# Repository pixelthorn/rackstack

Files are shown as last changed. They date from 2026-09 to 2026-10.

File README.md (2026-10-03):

# rackstack

display

This repo is reorganized version of the [original repo](https://github.com/jazwa/rackstack) with some added rack mounts for personal use. 

### A modular 3d-printable mini rack system
- ***Mount Anything:*** Perfect for organizing SBCs, mini PCs, small switches, power hubs, etc.
- ***Fully customizable:*** Fully written in OpenSCAD. Everything, from the dimensions of the rack, to the roundness of the corners, can be modified with a simple code change.
- ***Printable from home:*** Designed to be printed with conventional FDM printers. Requires minimal supports when printing, and final assembly needs only a few easy-to-source parts. 
- ***No cage nuts:*** Sliding hex nut design for the front rails allows one to easily mount items, without dealing with cage nuts.
- ***Stackable:*** Individual racks can be easily stacked and fastened together. Mix and match different color and design combinations!

## Assembly

Pre-generated STLs for roughly 200mm^3 (mini), 180mm^3 (micro), and 100mm^3 (nano) rack frames can be found in the [stl](stl) dir.
These STLs are generated from the files in [rack/print](rack/print) - further information about printing these parts 
(supports, orientation) can be found in these files.

### Assembly Instructions
Please see [the assembly guide](./assembly-guide).

### BOM - Required Tools:
- 3d FDM Printer - build size requirements depend on configured rack profile
- M3 Allen Key (for constructing the rack)
- M4 Allen Key (for mounting rack-mount items)

### BOM - Single Rack:

| Item | Name | Quantity | Comment |
|---|---|---|---|
|  | M3x12 FHCS | 12 | Extras are useful and inexpensive. If you plan on eventually stacking multiple racks together, don't hesitate to get a lot more. |
|  | M3x16 FHCS | 16 | ☝️ |
|  | M3 hex nut | 28 | ☝️ |
|  | 3x10 steel dowel pin | 4 | 3mm diameter, 10mm height |
|  | 6x2 neodymium disc magnet | 8 | 6mm diameter, 2mm height |
|  | super glue | \>= 2ml  | Used to glue magnets to plastic |

### Printing - Single Rack:
| Part | Quantity |
|---|---|
| [Left Y-Bar](./rack/print/yBarLeft_P.scad) | 2 |
| [Right Y-Bar](./rack/print/yBarRight_P.scad) | 2 |
| [X-Bar](./rack/print/xBar_P.scad) | 4 |
| [Main Rail](./rack/print/mainRail_P.scad) | 4 |
| [Left Side Wall](./rack/print/sideWallLeft_P.scad) | 1 |
| [Right Side Wall](./rack/print/sideWallRight_P.scad) | 1 |
| [XY-Plate](./rack/print/xyPlate_P.scad) | 2 |
| [Feet](./rack/print/rackFeet_P.scad) (optional) | 2 |

#### Notes: 
- ⚠️ Before printing the actual parts. It's recommended to print this evaluation part: [eval_P.scad](./rack/print/eval_P.scad) to test tolerances. 
  If you find the fits too tight/loose, you can adjust them [here](./config/print.scad). Please make sure also adjust the layer height in that file, too.
- Omitted actual plastic for printing. Any conventional 3d printing plastic should do (PLA, PETG, ABS),
but beware of PLA's thermal limits. Higher infill is recommended for all parts.
- For joining two racks, you will need to print 4 [rackJoiners](./rack/print/rackJoiner_P.scad), as well as 8 M3 hex nuts, and 8 M3x12 FHCS.
- Main front rails use M4 hex nuts and screws.
- Side rails are mounted using M3 hex nuts and screws.

## Configuring + Generating STLs
A python script:  [rbuild.py](./rbuild.py) is provided to generate different project stls. **Before running the script**, please 
configure the path to the OpenSCAD binary in [rbuild.py](./rbuild.py).

Requirements:
  - `openscad` CLI binary
  - `python3`

### Examples:
Generate all project files for the `micro` profile:

`python3 rbuild.py -b all -c micro`

This will build all the parts defined in [rack/print](./rack/print), and put the STLs in [stl/micro](./stl/micro). 
You can also provide a `-dz {n}` parameter to adjust the height of the generated rack. Configuring other rack
variables can be done in [config/rackframe.scad](./config/rackFrame.scad).

For generating a specific part, and putting it into a new `stl/custom` target directory: 

`python3 rbuild.py -b yBar -c micro -t custom`

`rbuild.py` also support an optional `--nightly` flag, which will run a nightly build of OpenSCAD. Please make sure the
path to the nightly build is also configured in [rbuild.py](./rbuild.py).

### ⚠️ Important:
Before committing to a full print, please try printing an evaluation print: [eval_P.scad](./rack/print/eval_P.scad) to test tolerances.
It is very likely you will need to edit the default tolerances in [print.scad](./config/print.scad) for a nice fit.
Confirm that your screw and nut sizes in [screws.scad](helper/screws.scad) and adjust if needed. Nuts, especially, may vary slightly.

## Trays, Boxes, etc

Some parametric rack mount systems can be found in [rack-mount](./rack-mount). The following rack-mount systems 
are currently supported:
- [Enclosed Box](./rack-mount/boxes/enclosed-box): For mounting box-shaped objects, without the need for any mounting holes on the box.
- [Tray](./rack-mount/trays/tray): Simple tray mounted using only the front rails. Can be configured to have screw mounts at the bottom of the tray.
- [Patch Panel](./rack-mount/panels/patch-panel): Linear patch panel array. Number of keystone slots can be configured.
- [Angle Brackets](./rack-mount/angle-bracket): Simple Angle Bracket mounting system. Derived from the Enclosed Box system.

Additional user generated mounts can be found under [rack-mount](./rack-mount) as well. 

### Generating STLs for Rack Mount parts

Make sure that the correct profileName is set in [rackframe.scad](./config/rackFrame.scad)! 
Use OpenSCAD or another CAD program to open entry.scad (or other main scad file) in the subfolder and render it then export as STL.

## Designing rack-mount items

Some useful variables for designing your own rack-mount items can be found in [rack-mount/dimensionHelper.scad](./rack-mount/dimensionHelper.scad).

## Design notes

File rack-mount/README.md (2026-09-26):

# Rack Mount Catalog

A hodgepodge of various pre-configured rack mount parts. 

Command to rebuild the preview images:
`find . -name "*.scad" -exec ./build_catalog_preview.sh {} \;`

Rebuild a single image:
`./build_catalog_preview.sh <path/to/filename.scad`

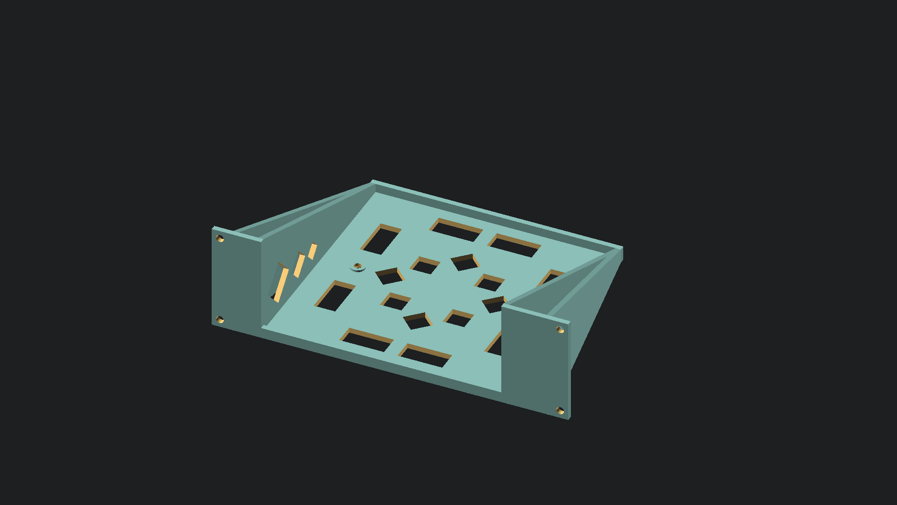
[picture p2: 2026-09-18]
rack-mount/trays/Minisforum_NAB9_tray/Minisforum_NAB9-tray_mod.png

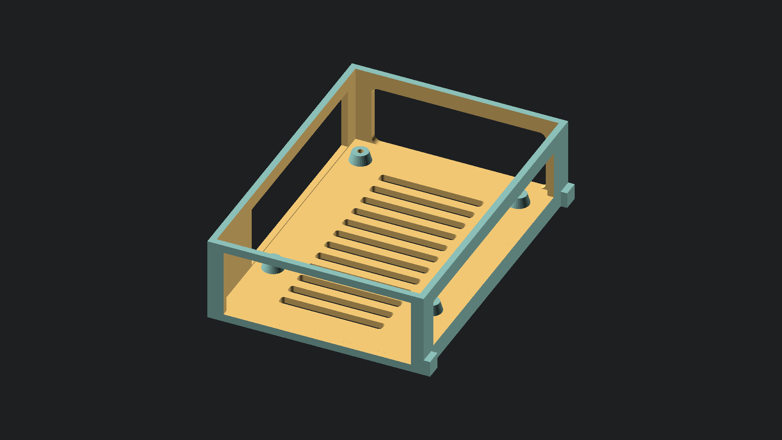
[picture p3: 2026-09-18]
rack-mount/boxes/rpi-sbc-simple-box/case.png

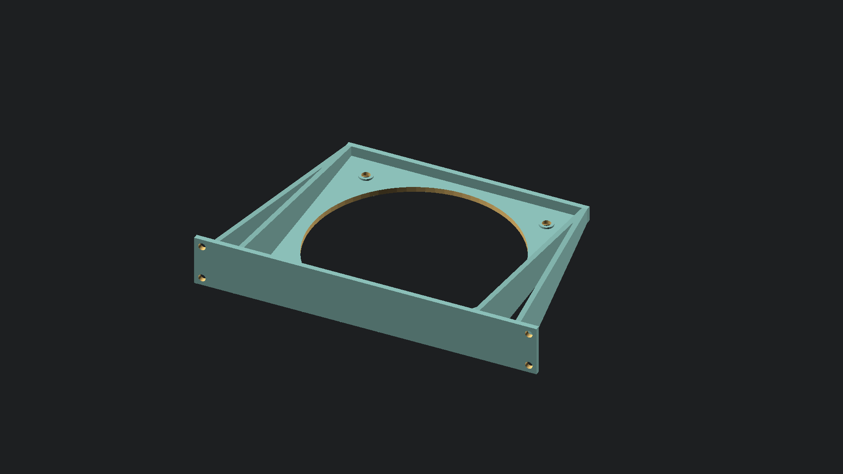
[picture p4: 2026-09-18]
rack-mount/trays/120mm_fan_tray/120mm-fan-tray_mod.png

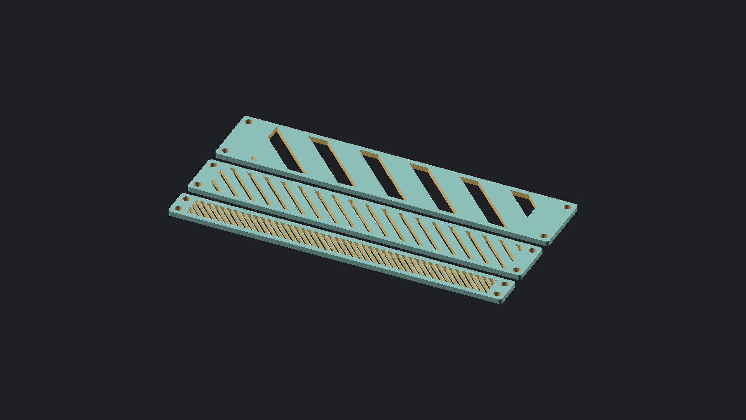
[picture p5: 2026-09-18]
rack-mount/plates/ventilated-plate/ventilated_plate.png

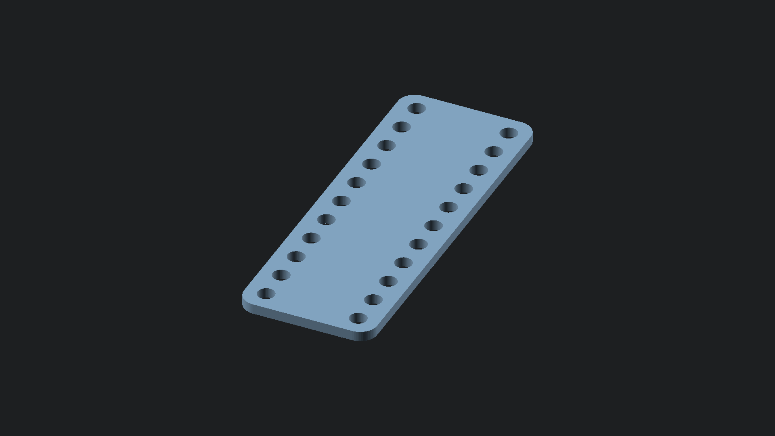
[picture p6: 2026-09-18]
rack-mount/plates/screw-plate/screwplate.png

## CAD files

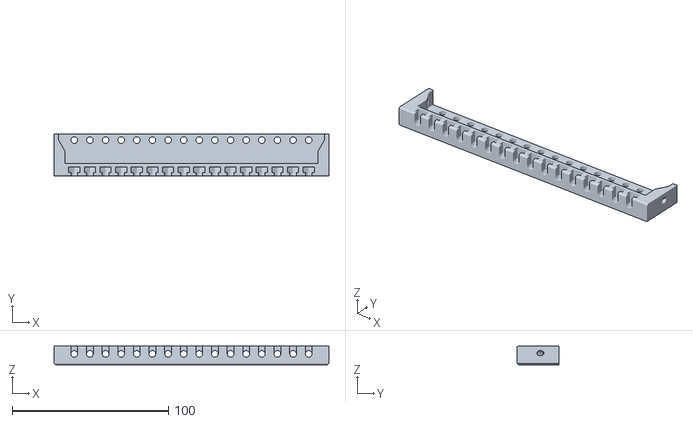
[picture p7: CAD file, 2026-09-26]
stl/mini/rack/mainRail_P.stl
176.0 x 27.0 x 12.0

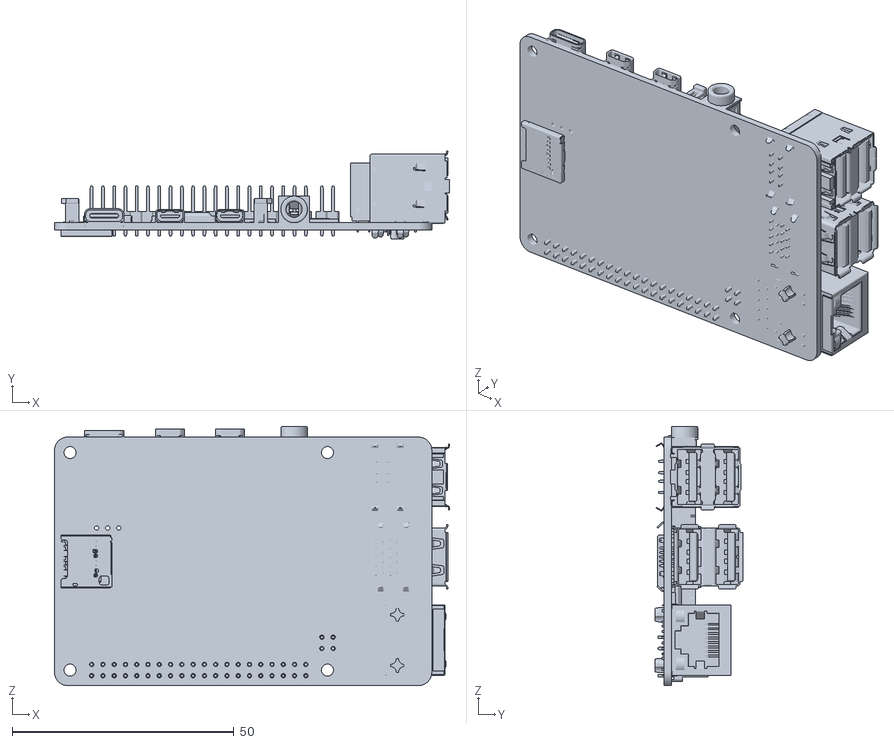
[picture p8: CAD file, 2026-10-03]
rack-mount/trays/raspberry_pi_4b_tray/Raspberry Pi 4 Model B.stl
89.0 x 19.9 x 58.4

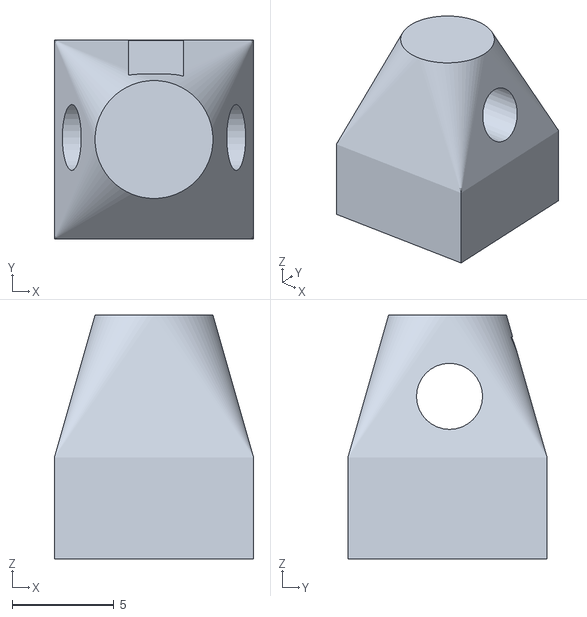
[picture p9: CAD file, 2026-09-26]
stl/mini/rack/stackConnectorBottom_P.stl
9.80 x 9.80 x 12.0

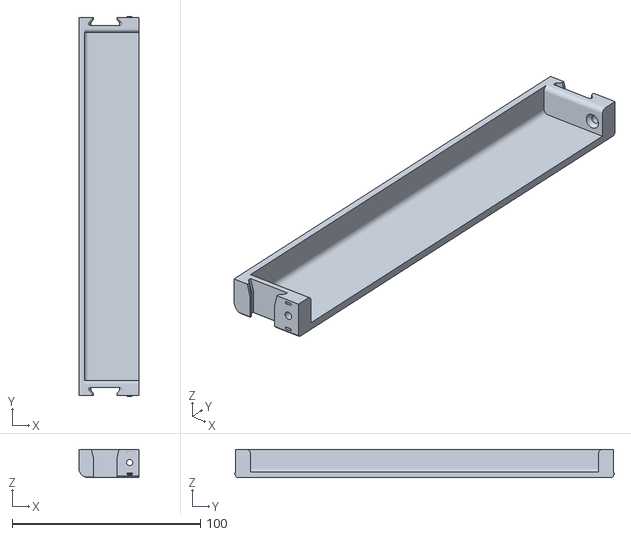
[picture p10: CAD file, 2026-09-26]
stl/mini/rack/xBar_P.stl
32.0 x 201.8 x 15.0

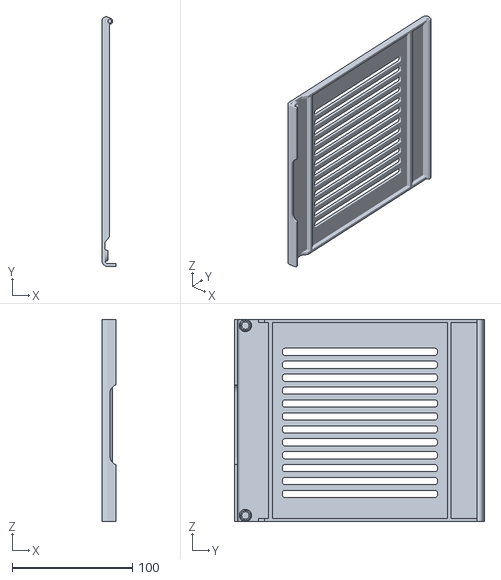
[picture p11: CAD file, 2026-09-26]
stl/mini/rack/sideWallLeft_P.stl
11.8 x 208.3 x 168.4

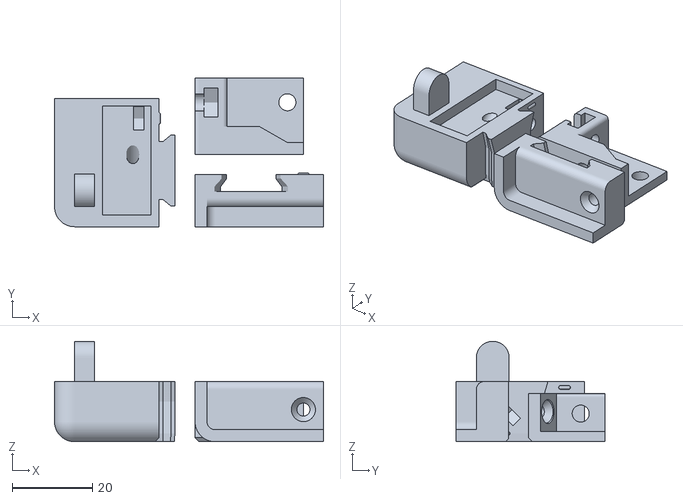
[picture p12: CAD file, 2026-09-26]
stl/mini/rack/eval_P.stl
67.0 x 37.0 x 25.0

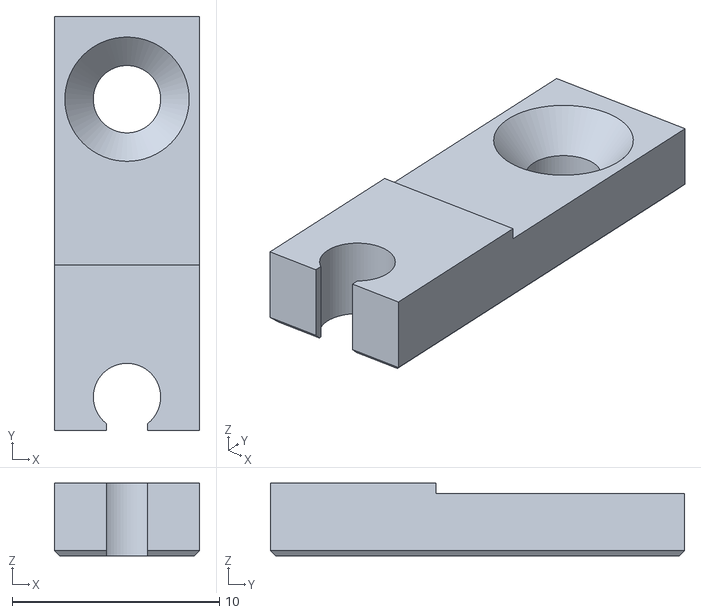
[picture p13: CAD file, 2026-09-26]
stl/mini/rack/hingeModule.stl
7.00 x 20.0 x 3.50

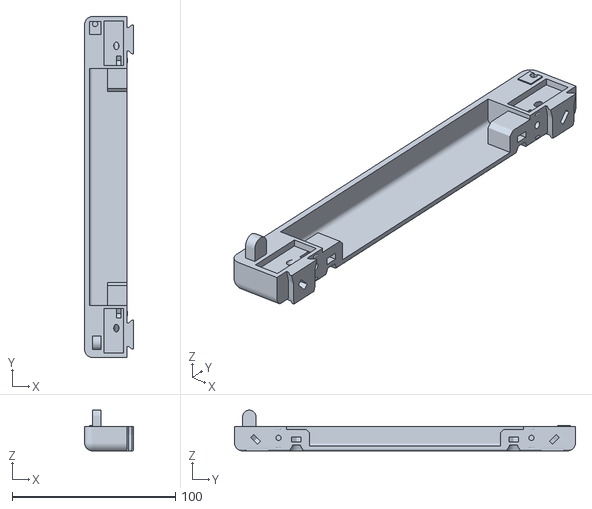
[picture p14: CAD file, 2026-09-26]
stl/mini/rack/yBarLeft_P.stl
30.0 x 209.0 x 25.0

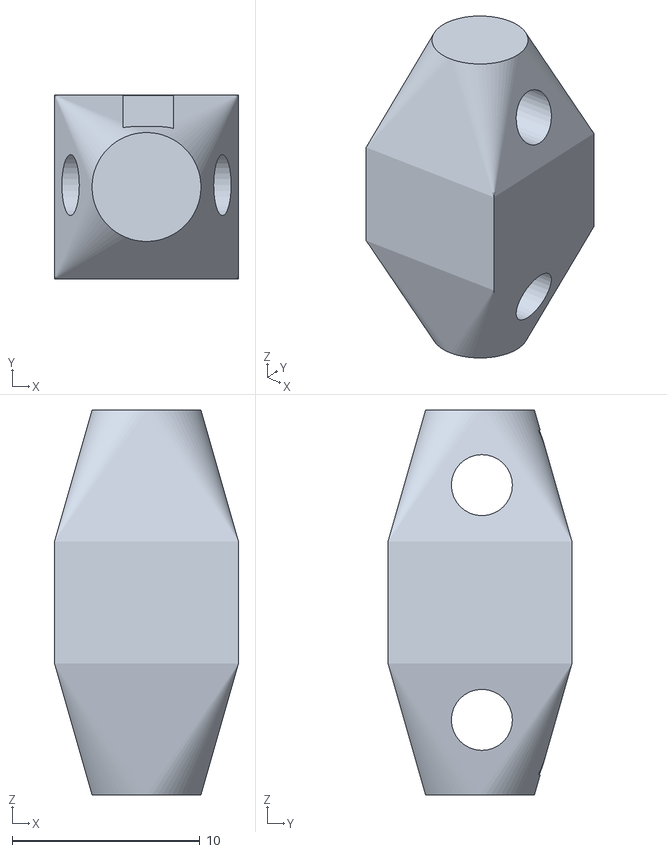
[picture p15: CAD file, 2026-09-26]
stl/mini/rack/rackJoiner_P.stl
9.80 x 9.80 x 20.5

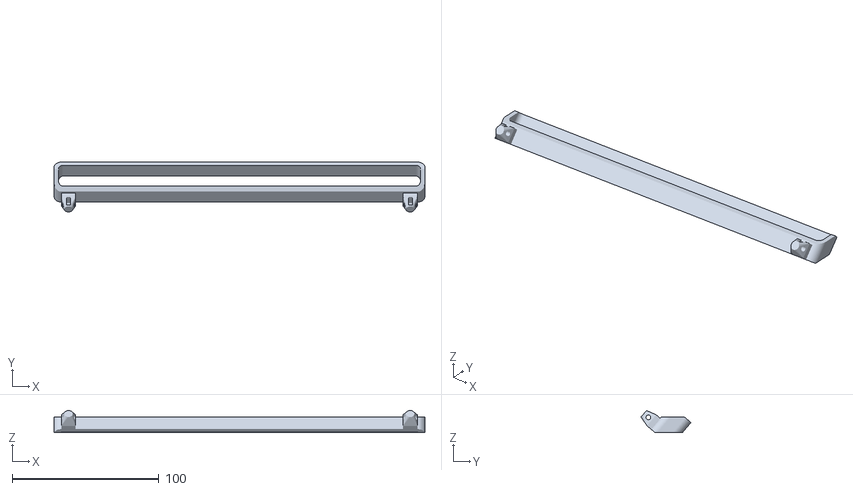
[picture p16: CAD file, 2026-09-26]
stl/mini/rack/rackFeet_P.stl
253.0 x 34.0 x 15.0

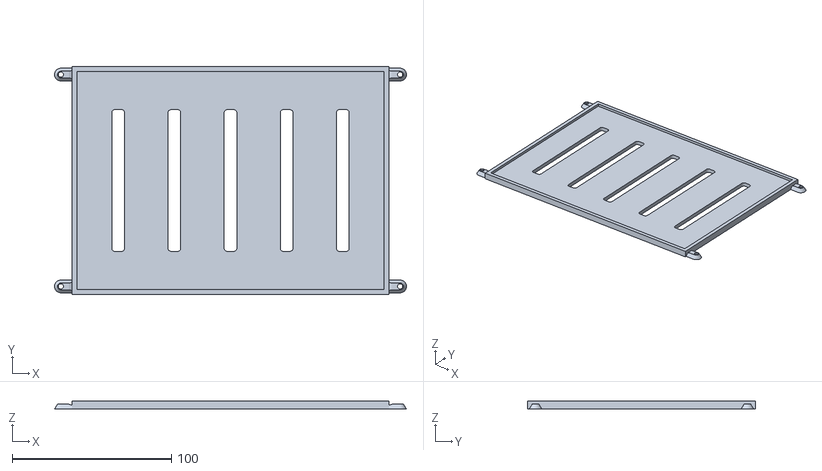
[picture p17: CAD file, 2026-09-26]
stl/mini/rack/xyPlate_P.stl
221.0 x 143.0 x 5.00

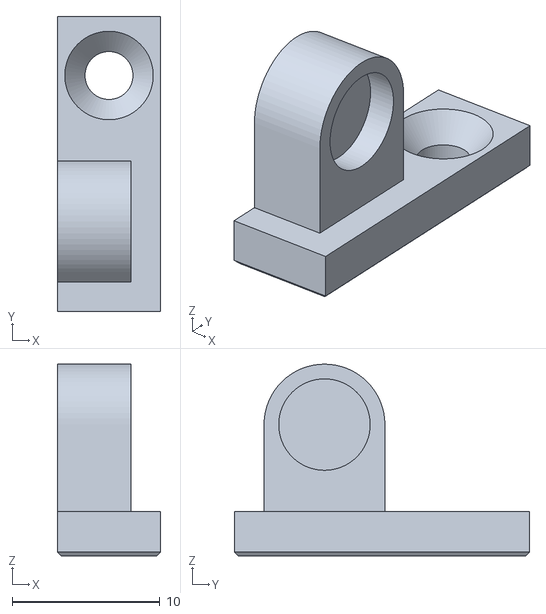
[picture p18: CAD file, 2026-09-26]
stl/mini/rack/magnetModuleRight_P.stl
7.00 x 20.0 x 13.0

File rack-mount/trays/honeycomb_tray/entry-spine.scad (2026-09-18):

use <./tray-honeycomb-spine.scad>

/*
  Parametric rack-mount tray:
  Dimensions can be adjusted using the variables below. You can also add mounting holes to fasten things that have
  screw holes at the bottom.

  !!! Please also make sure that the correct rack frame preset is set in rackFrame.scad !!!
*/

module traySystem (

trayU = 2,

baseWidth = 195,
baseDepth = 185,

baseThickness = 3,
frontThickness = 3,
sideThickness = 3,

backLipHeight = 2,
frontLipHeight = 2,

sideSupport = false,
trayLeftPadding = 10,

mountPointType = "m3",
mountPointElevation = 1,

mountPoints = [],

// Honeycomb
hex_side = 4.0,
cell_wall = 1.5,
rim_width = 3.0

) {

  bottomScrewTray (
    u = trayU,
    trayWidth = baseWidth,
    trayDepth = baseDepth,
    trayThickness = baseThickness,
    frontLipHeight = frontLipHeight,
    backLipHeight = backLipHeight,
    mountPoints = mountPoints,
    frontThickness = frontThickness,
    sideThickness = sideThickness,
    mountPointElevation = mountPointElevation,
    mountPointType = mountPointType,
    sideSupport = sideSupport,
    trayLeftPadding = trayLeftPadding,
    hex_side = hex_side,
    cell_wall = cell_wall,
    rim_width = rim_width
  );
}

traySystem();

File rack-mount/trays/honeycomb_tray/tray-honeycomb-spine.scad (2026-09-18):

include <../../common.scad>
use <../../rackEars.scad>

// --- honeycomb helpers, lifted from catalog/honeycomb-tray/entry.scad ---
module __hex2d(side) {
    polygon(points=[ for (i=[0:5]) [ side*cos(60*i), side*sin(60*i) ] ]);
}

module __honeycomb_plate(width, depth, plate_h, side, wall, rim, spine_x=-1, spine_w=0) {
    difference() {
        cube([width, depth, plate_h], center=false);
        x_step = 1.5 * side;
        y_step = sqrt(3) * side;
        w = width - 2*rim;
        d = depth - 2*rim;
        translate([rim, rim, 0])
        union() {
            for (ix = [0 : ceil(w / x_step) + 1]) {
                x = side + ix * x_step;
                y_off = (ix % 2) * (y_step/2);
                for (iy = [0 : ceil(d / y_step) + 1]) {
                    y = y_off + iy * y_step;
                    // skip any hex whose center falls inside the spine band
                    inSpine = (spine_w > 0) && (abs((x+rim) - spine_x) < spine_w/2 + side);
                    if (x >= 0 && x <= w && y >= 0 && y <= d && !inSpine) {
                        translate([x, y, 0])
                            linear_extrude(height=plate_h + 0.05)
                                __hex2d(max(0.01, side - wall));
                    }
                }
            }
        }
    }
}

module bottomScrewTray(u, trayWidth, trayDepth, trayThickness, mountPoints, mountPointElevation, mountPointType, frontThickness, sideThickness, frontLipHeight, backLipHeight, trayLeftPadding, sideSupport=true,
  hex_side=6, cell_wall=1.5, rim_width=3) {   // <-- new honeycomb params

  lipThickness = sideThickness;
  screwDx = rackMountScrewWidth;
  screwDz = uDiff * u;
  plateLength = screwDx + 2*rackMountScrewXDist;
  plateHeight = screwDz + 2*rackMountScrewZDist;
  minScrewToTraySpacing = railScrewHoleToInnerEdge;
  leftScrewDistToTray = minScrewToTraySpacing + trayLeftPadding;
  leftScrewGlobalX = -leftScrewDistToTray;
  rightScrewGlobalX = screwDx + leftScrewGlobalX;

  assert(trayWidth <= screwDx-(2*minScrewToTraySpacing + trayLeftPadding));

  difference() {
    applyMountHoles()
    translate(v = [-sideThickness, -frontThickness, -trayThickness])
    body();
  }

  module body() {

    // honeycomb base instead of a solid cube
    __honeycomb_plate(trayWidth, trayDepth, trayThickness, hex_side, cell_wall, rim_width, spine_x=trayWidth/2, spine_w=14);

    // front lip
    translate(v = [0, 0, trayThickness])
    cube(size = [trayWidth, lipThickness, frontLipHeight]);

    // back lip
    translate(v = [0, trayDepth-lipThickness, trayThickness])
    cube(size = [trayWidth, lipThickness, backLipHeight]);

    translate(v = [leftScrewGlobalX, 0, rackMountScrewZDist])
    rackEarModule(frontThickness = frontThickness, sideThickness = sideThickness, frontWidth =
        leftScrewDistToTray+rackMountScrewXDist+sideThickness, sideDepth = trayDepth-lipThickness, u = u, backPlaneHeight=trayThickness+backLipHeight, support=sideSupport);

    translate(v = [rightScrewGlobalX, 0, rackMountScrewZDist])
    mirror(v = [1, 0, 0])
    rackEarModule(frontThickness = frontThickness, sideThickness = sideThickness, frontWidth =
       rightScrewGlobalX-trayWidth+rackMountScrewXDist+sideThickness, sideDepth = trayDepth-lipThickness, u = u, backPlaneHeight=trayThickness+backLipHeight, support=sideSupport);
  }

  module applyMountHoles() {
    mountPointPosThickness = 2;
    if (len(mountPoints) > 0) {
      apply_pn() {
        for (i = [0:len(mountPoints)-1]) {
          x = mountPoints[i][0]; y = mountPoints[i][1];
          translate(v = [x, y, 0])
          cylinder(r = screwRadiusSlacked(mountPointType)+mountPointPosThickness, h = mountPointElevation);
        }
        for (i = [0:len(mountPoints)-1]) {
          x = mountPoints[i][0]; y = mountPoints[i][1];
          translate(v = [x, y, -trayThickness])
          mirror(v = [0, 0, 1])
          counterSunkHead_N(mountPointType, inf, inf);
        }
        children(0);
      }
    } else {
      children(0);
    }
  }
}

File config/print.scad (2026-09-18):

// Print settings config file

/**********************************************************************************************************************
  Slack config to standardize different usages of slack/tolerance values.

  The purpose of this config is to introduce some consistency with how slack values defined in code. E.g. Why is the
  slack value defined as 0.3 in this file, but 0.4 in another? This will also allow model-level adjustments for tighter
  fitting parts, for when it might not convenient to adjust the actual 3d printer (using a 3d printer at a makerspace,
  for example).

  Some important details:
    - The general philosophy for slack applications in this project is to subtract space from sockets, while not
      modifying the plugs.
    - Values are signed. Positive values can be interpreted as how much to remove from the socket along some dimension.
    - These values depend on print orientation and it's assumed parts are printed in their recommended orientations.
*/
xySlack = 0.25;

radiusXYSlack = xySlack/2;

zSlack = 0.0;

overhangSlack = 0.5;

supportedOverhangSlack = 0.5;

// special slack cases, change if neccessary
xBarYBarDovetailSlack = xySlack;

/**********************************************************************************************************************
  Printer/slicer config, mainly used for calculating some special overhangs.
*/
defaultLayerHeight = 0.2;

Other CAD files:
stl/mini/rack/sideWallRight_P.stl
stl/mini/rack/yBarRight_P.stl
stl/mini/rack/magnetModuleLeft_P.stl
config/rackFrame.scad
helper/screws.scad
misc/component.scad
misc/device_raspberrypi.scad
misc/misc_boards.scad
misc/misc_parts.scad
rack-mount/angle-bracket/entry.scad
rack-mount/angle-bracket/entry_customizers.scad
rack-mount/boxes/enclosed-box/animate.scad
rack-mount/boxes/enclosed-box/entry.scad
rack-mount/boxes/enclosed-box/entry_customizers.scad
rack-mount/boxes/enclosed-box/entry_plate_only.scad
rack-mount/boxes/enclosed-box/frontBoxHolder.scad
rack-mount/boxes/enclosed-box/helper.scad
rack-mount/boxes/enclosed-box/sideRail.scad
rack-mount/boxes/rpi-sbc-simple-box/case.scad
rack-mount/boxes/rpi-sbc-simple-box/frontPlate.scad
rack-mount/boxes/rpi-sbc-simple-box/top.scad
rack-mount/boxes/sfxPSU/sfxPSU.scad
rack-mount/boxes/single-bracket-box/entry.scad
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

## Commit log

2026-09-18 organized rack-mount items into subdirectories
    [10-zoll_Raspberry_pi_4-DualMount_ohne_text.3mf, 10-zoll_Raspberry_pi_4-DualMount_ohne_text.scad, 10-zoll_Raspberry_pi_4-DualMount_ohne_text.stl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]
2026-09-18 removed unneeded file
    [simple_tray.scad]
2026-09-18 updated dimensions
    [print.scad, screws.scad]
2026-09-18 added png files
    [10-zoll_Raspberry_pi_4-DualMount_ohne_text.3mf, 10-zoll_Raspberry_pi_4-DualMount_ohne_text.scad, 10-zoll_Raspberry_pi_4-DualMount_ohne_text.stl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]
2026-09-26 updated m3 screw nut size and regenerated min rack stl
    [eval_P.stl, hingeModule.stl, magnetModuleLeft_P.stl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]
2026-09-26 made the mini rack the default
    [rackFrame.scad]
2026-09-26 added more dimensions
    [dimensionHelper.scad]
2026-09-26 adjusted screwplate to allow different parameters for right and left sides
    [screwplate.scad]
2026-09-26 added width check
    [brush-strip-plate.scad]
2026-09-26 updated vented bracket tray; added tray with no bracket fro separating the print
    [entry_no_bracket.scad]
2026-09-26 updated comments
    [entry.scad]
2026-09-26 adjusted comments and padding; created image
    [enclosed_tray.scad, entry.scad]
2026-09-26 updated code to be more robust and to add warnign for bad dimensions
    [ventilated_plate.scad]
2026-09-26 initial code for small box on a single bracket
    [entry.scad]
2026-09-26 cleaned up comments, changed width
    [entry.scad]
2026-10-03 updated scad files tor eflect new locations
    [RasPi_4B_-_3U-rack.scad, Raspberry Pi 4 Model B.stl, entry.scad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]
2026-10-03 added raspberry pi files
    [component.scad, device_raspberrypi.scad, misc_boards.scad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]
2026-10-04 adjusted how slots are rendered
    [entry.scad]
